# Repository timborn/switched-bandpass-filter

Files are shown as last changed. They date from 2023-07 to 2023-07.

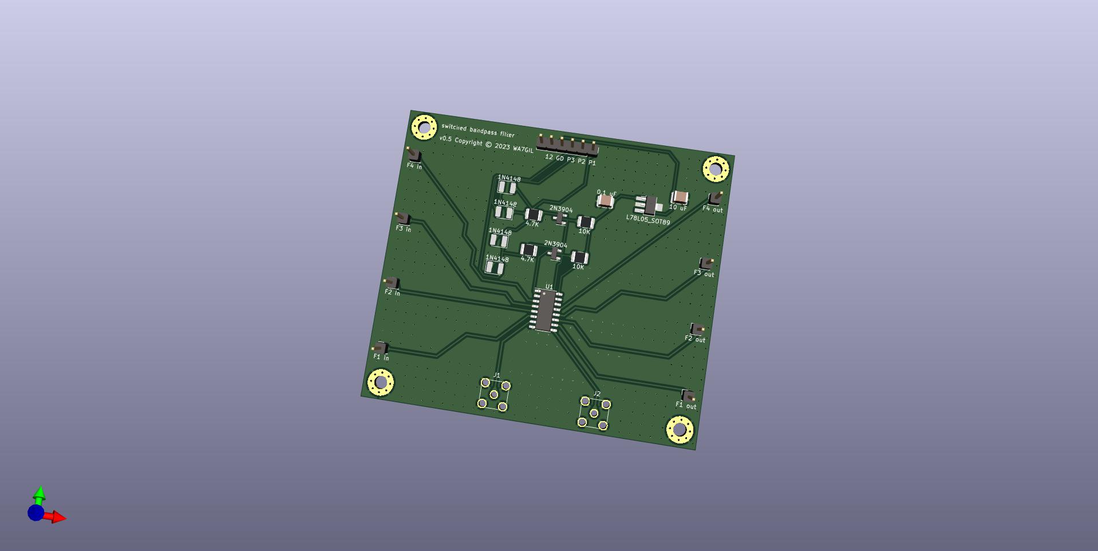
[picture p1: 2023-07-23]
docs/v0.5 3D front.jpg

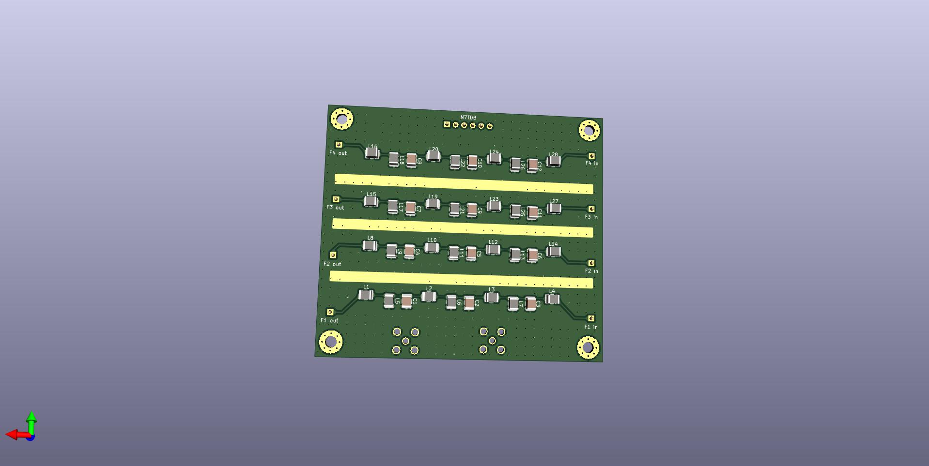
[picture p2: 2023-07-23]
docs/v0.5 3D back.jpg

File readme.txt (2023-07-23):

Thu Jul 20 09:18:21 MST 2023
----------------------------
Ron dropped off a couple of pages of hand drawn sketchs to make into a board.

CHANGE REQUESTS
X. change 4-pin header to 6-pin header
    Ron Taylor, 230719 4:47 PM
    Already thought I’d something. Please make it a 6pin header for the 
    switching so we can reference ground and have a spare too. Thanks
    
    tim born, 230719 4:48 PM
    6 pins instead of 4?  got it
2. correct board size appears to be 82x56mm
X. make sure to label Fx in/out on back of board!
4. DRC "solder mask aperture bridges items with different nets"
   SOT89 for 7805 has no solder bridge between pads for SMT part.
   I turned this error into a warning.  Don't know what I can do 
   to actually fix this.
X. fix this: single branch only using master
X. get rid of traces from front that route on the back
7. spread the connections from Fx in/out to U1 further apart
X. may not need full 15mm width for each of the filter runs
   squeeze them in and let Ron inspect
   we basically have a 56mm width minus SMA connectors minus headers
   there just isn't enough for 4*15mm filter strips
   Resolved: just jam them in.  Ron thinks they will fit.
X. increase board size and add mounting holes in the corners.
   3.25mm plated through and grounded, for 4-40 mounting h/w.
X. update board size on PCB viewer
X. traces to SMA are 50 ohm and need to be 3mm
X. add 3mm wide strips between filters by removing solder mask 
    so vertical boards could be soldered on
13. zeroed out "solder mask expansion" and "solder mask minimum web width"
    as I got stern warnings to use zero and let mfgr pick something suitable.
    Need to change the template.

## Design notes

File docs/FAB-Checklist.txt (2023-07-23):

Sun Jul 23 12:02:13 MST 2023
----------------------------

Checklist before you send it to the factory.

_X_ Update the page settings and version number on schematic & PCB.
    Check silkscreen version number!
_X_ ERC
_X_ Fill all pours!
_X_ run via stitcher
_X_ DRC
_X_ Generate Gerbers: 
    File / Plot  
    Layers: 
	F.Cu 
	B.Cu 
	F.Silkscreen 
	B.Silkscreen 
	F.Mask 
	B.Mask 
	Edge.Cuts
_X_ Generate Drill File.  Put output in same folder with Gerbers
_X_ verify Gerbers using Gerber Viewer in KiCad
    Suggested order: B.CU, B.Mask, B.Silkscreen, toggle each layer to 
    look for outliers.  Add Edge.Cuts.
    Repeat for F.*
_X_ zip up gerber/ into gerber.zip
_X_ PCBWAY
    NB anything but GREEN mask costs more!
    NB 83x73mm approx.  It's actually a couple mm larger than actual board.
_X_ git tag & push tags to origin

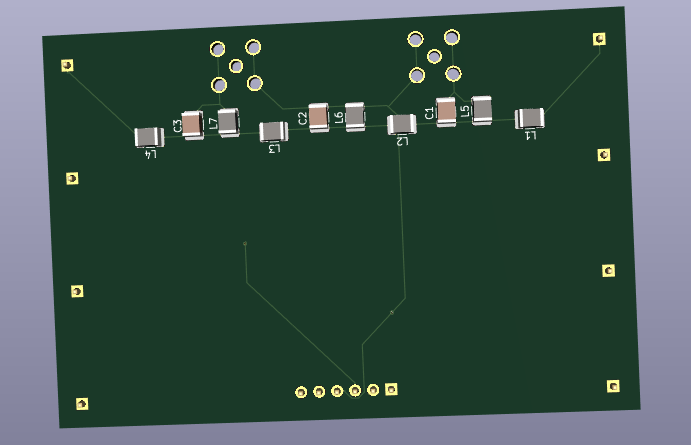
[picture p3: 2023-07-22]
docs/v0.2 3D back.png

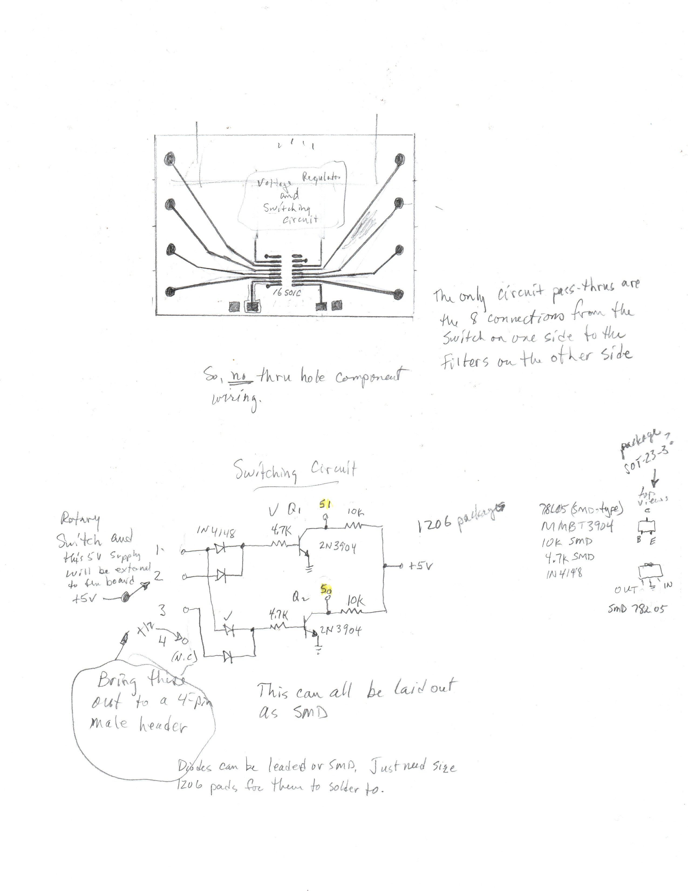
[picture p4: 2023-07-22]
docs/sketch-p1.jpg

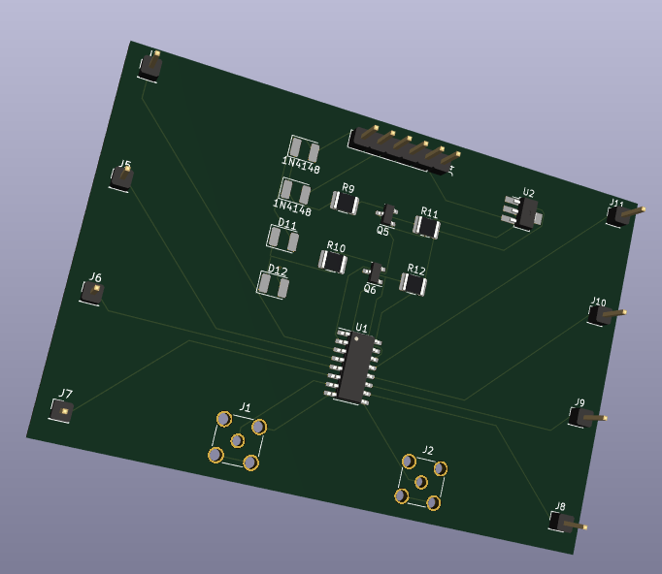
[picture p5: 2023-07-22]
docs/v0.2 3D front.png

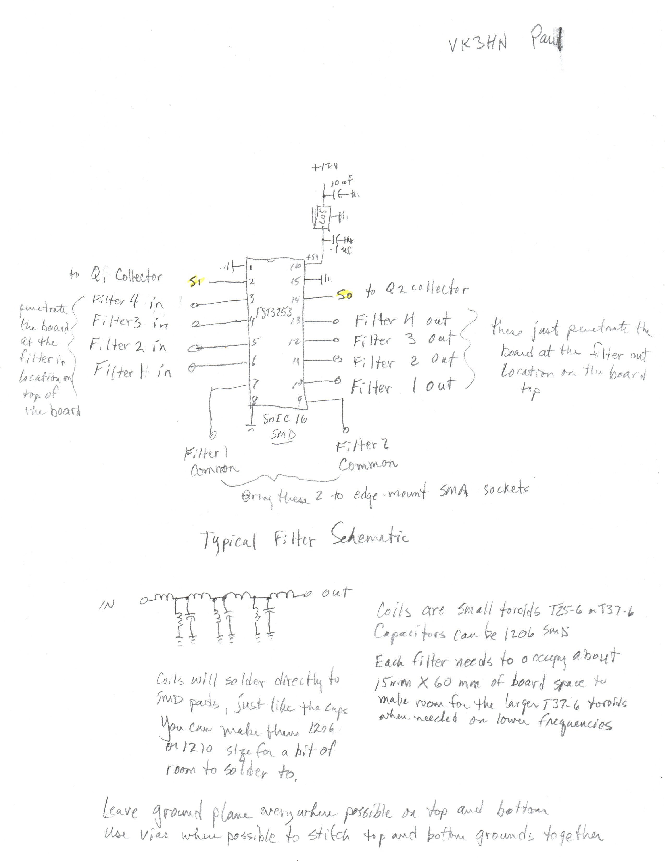
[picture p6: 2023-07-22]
docs/sketch-p2.jpg

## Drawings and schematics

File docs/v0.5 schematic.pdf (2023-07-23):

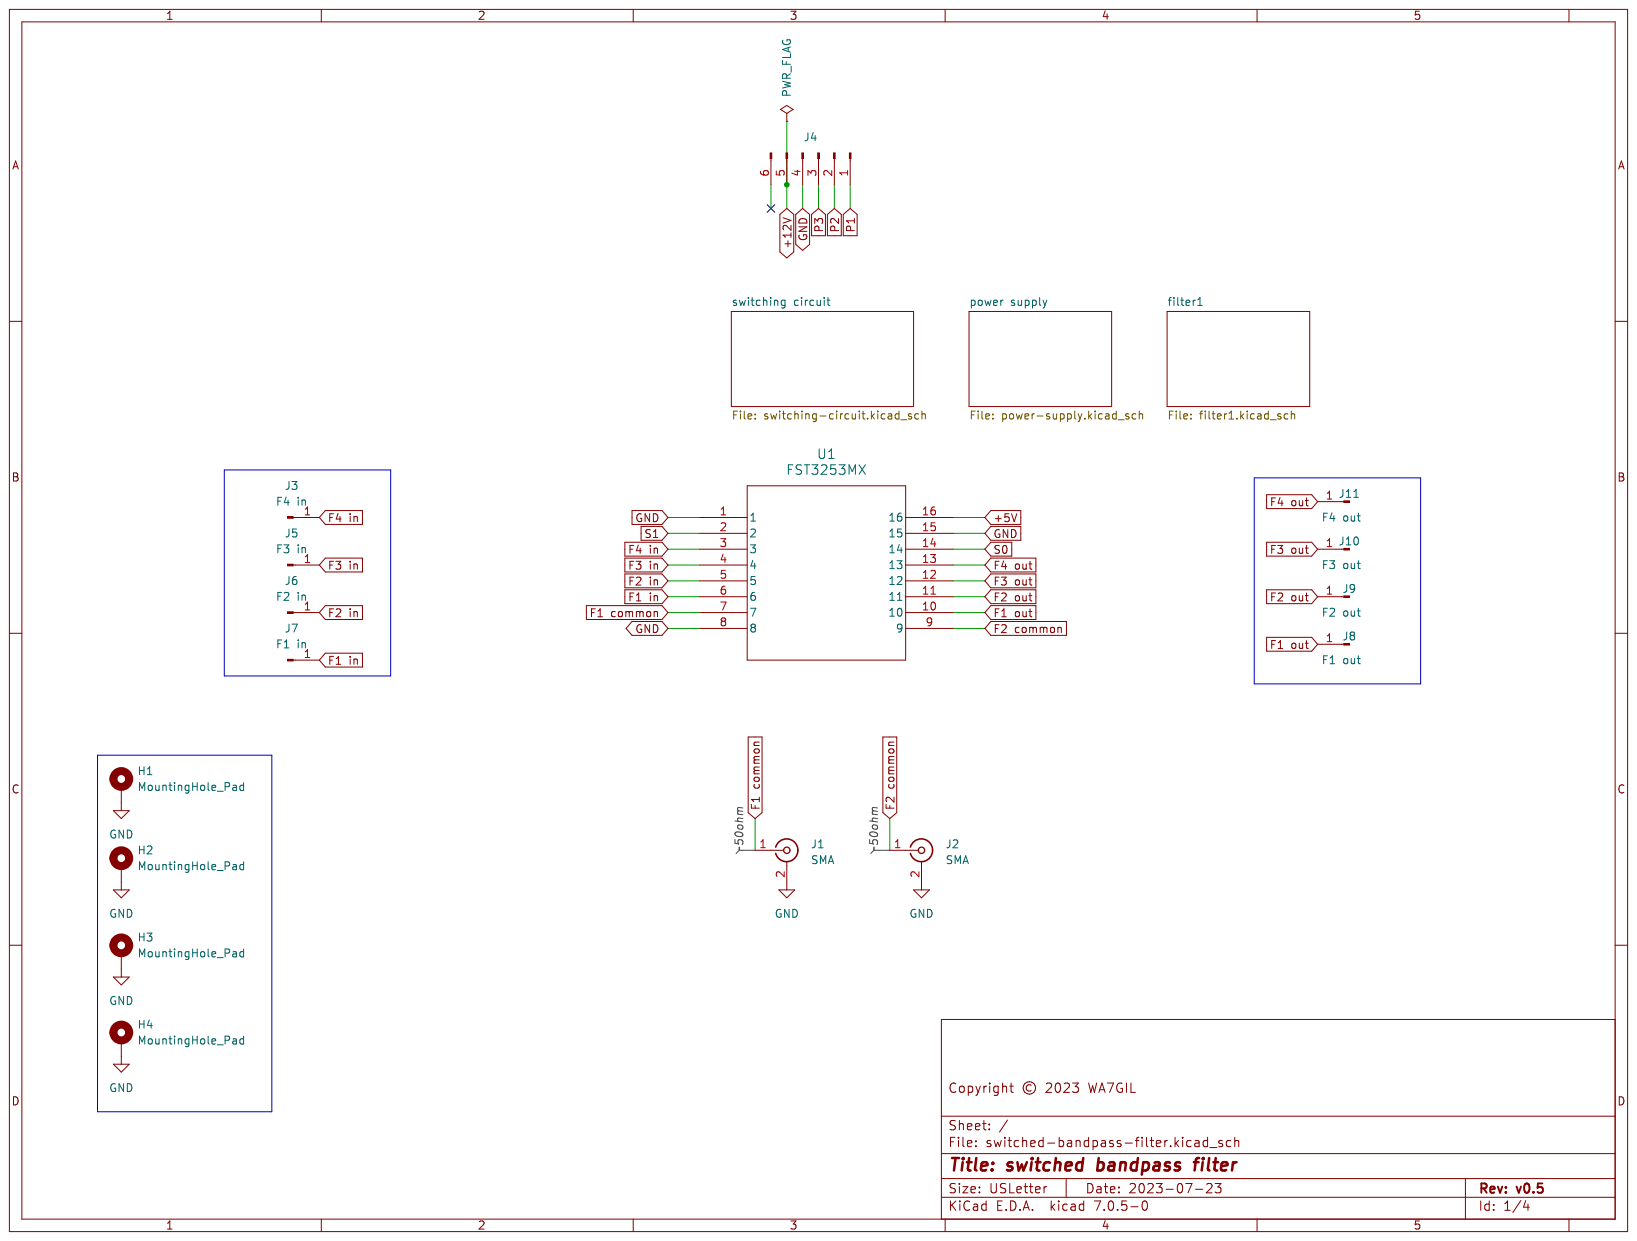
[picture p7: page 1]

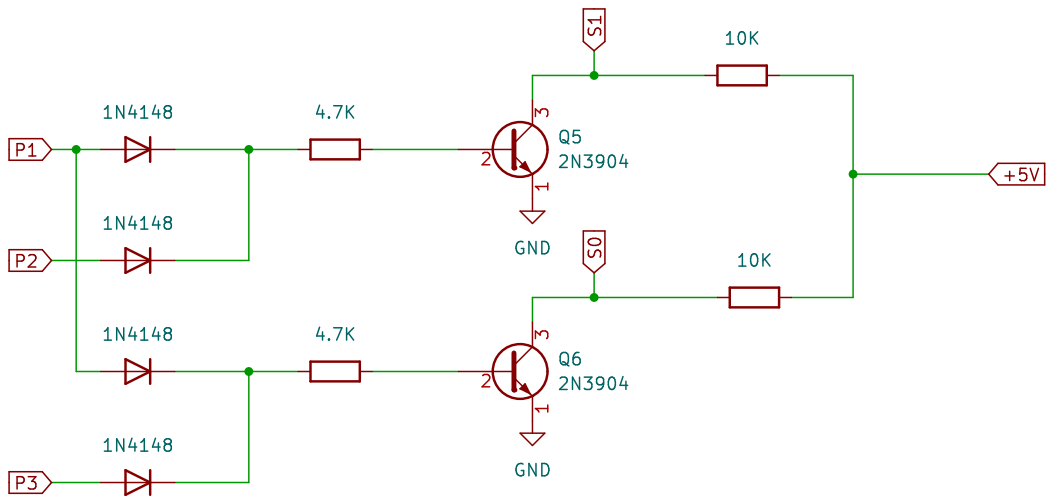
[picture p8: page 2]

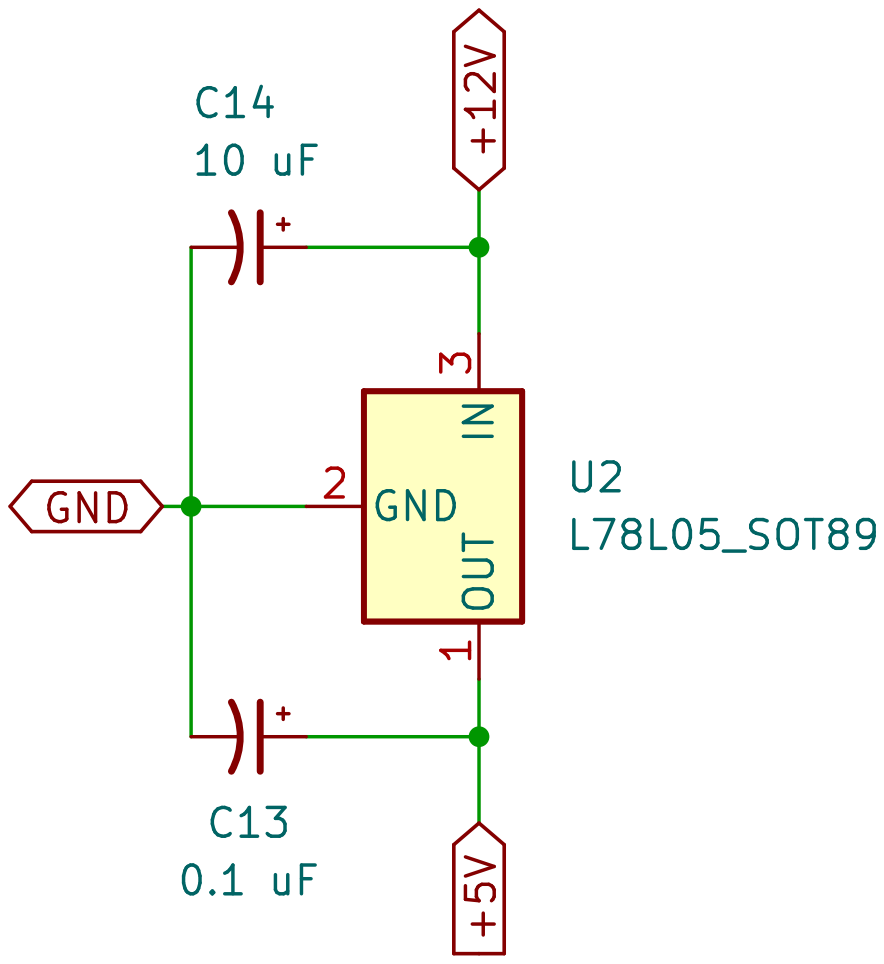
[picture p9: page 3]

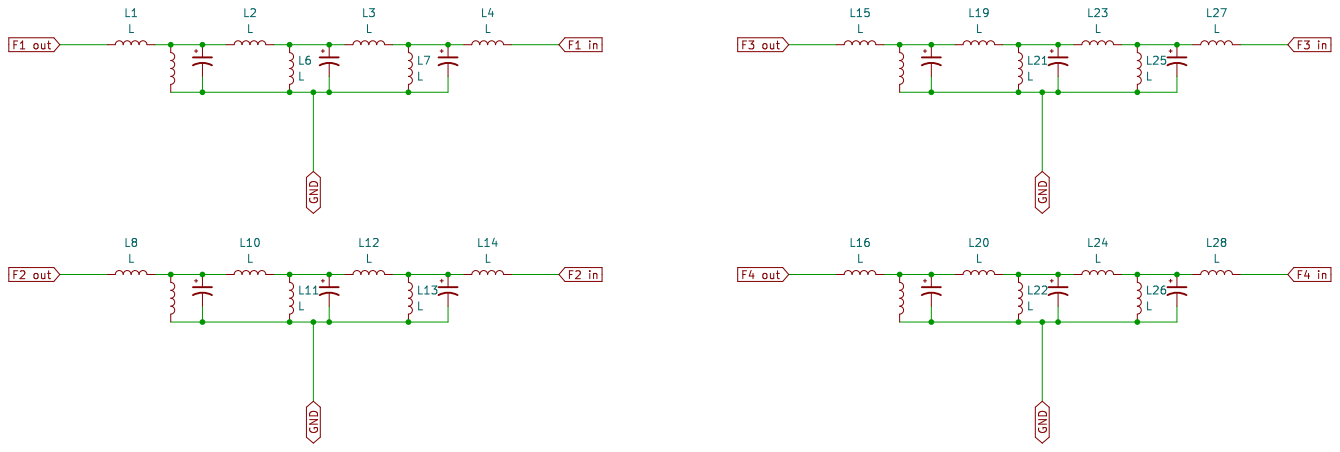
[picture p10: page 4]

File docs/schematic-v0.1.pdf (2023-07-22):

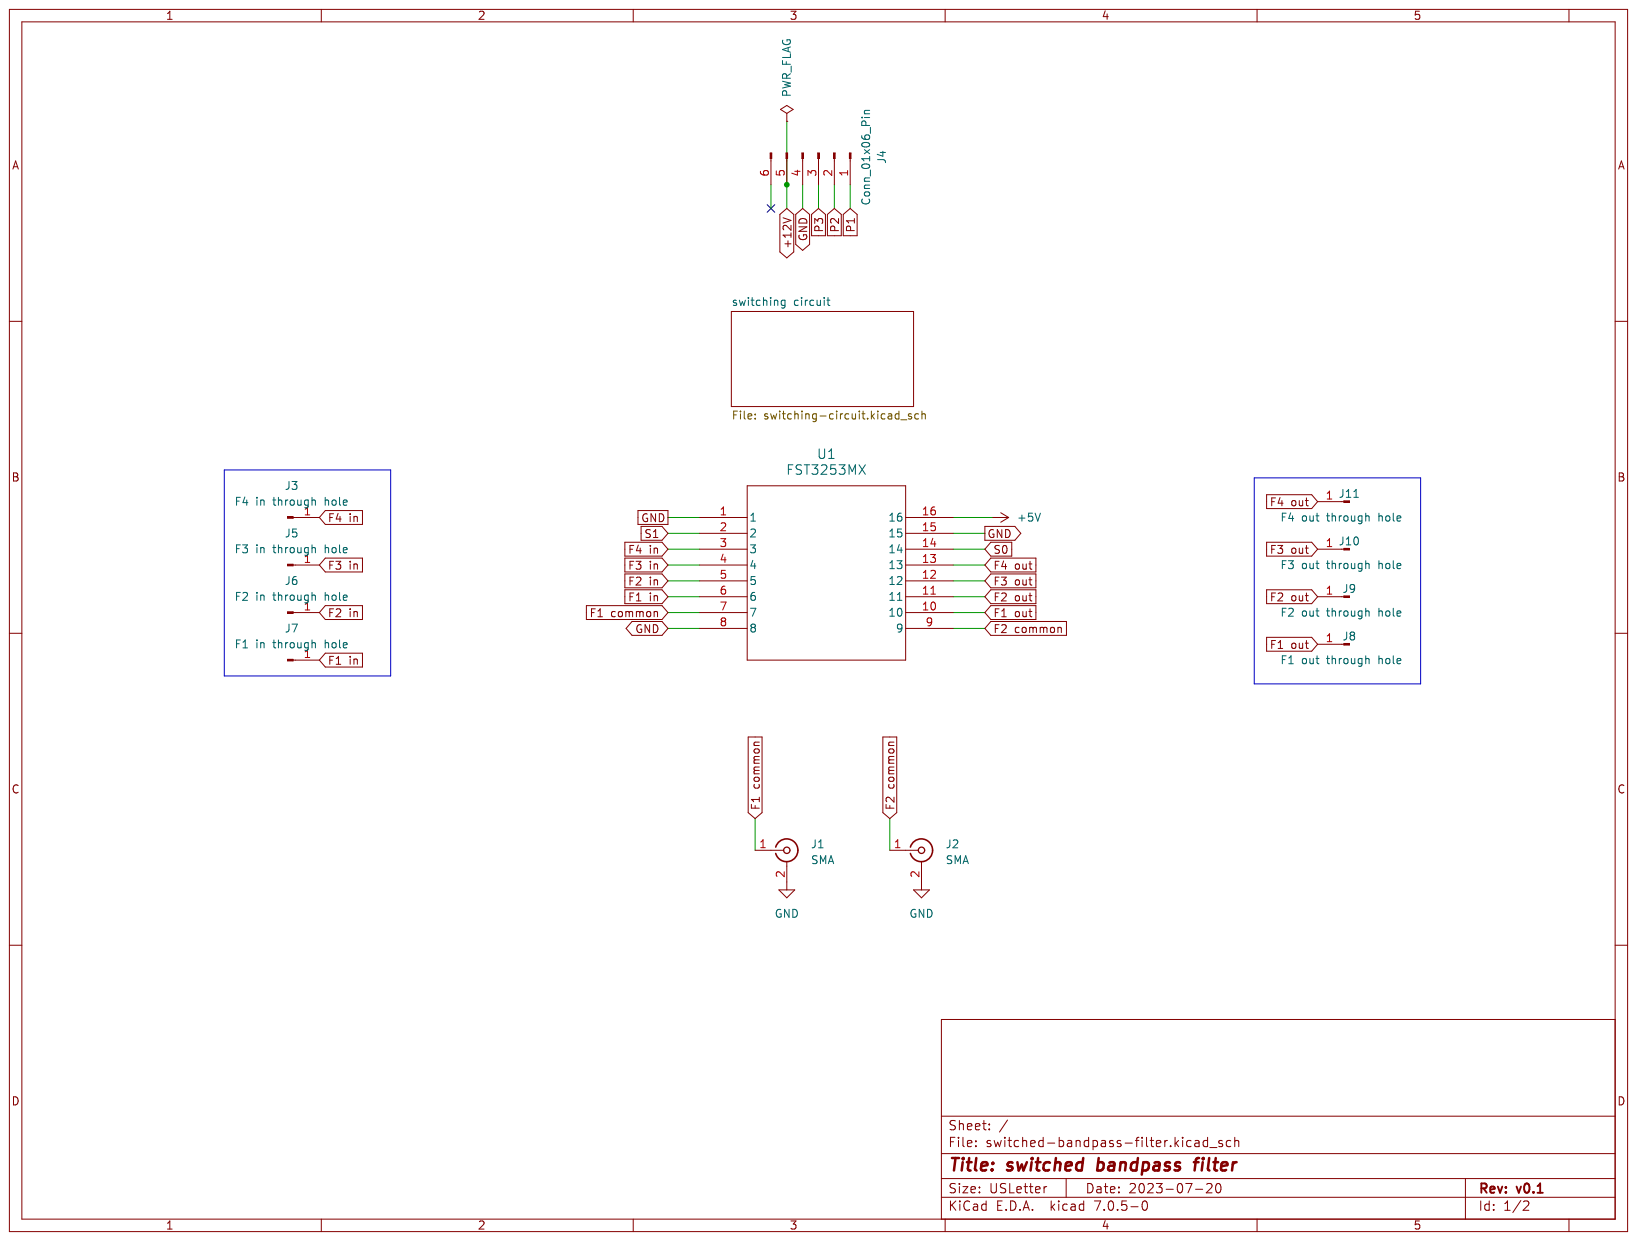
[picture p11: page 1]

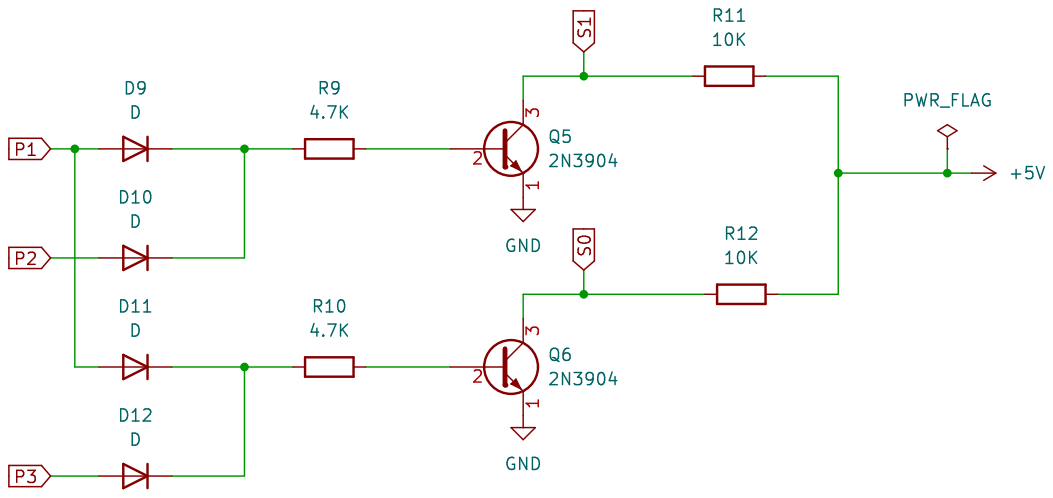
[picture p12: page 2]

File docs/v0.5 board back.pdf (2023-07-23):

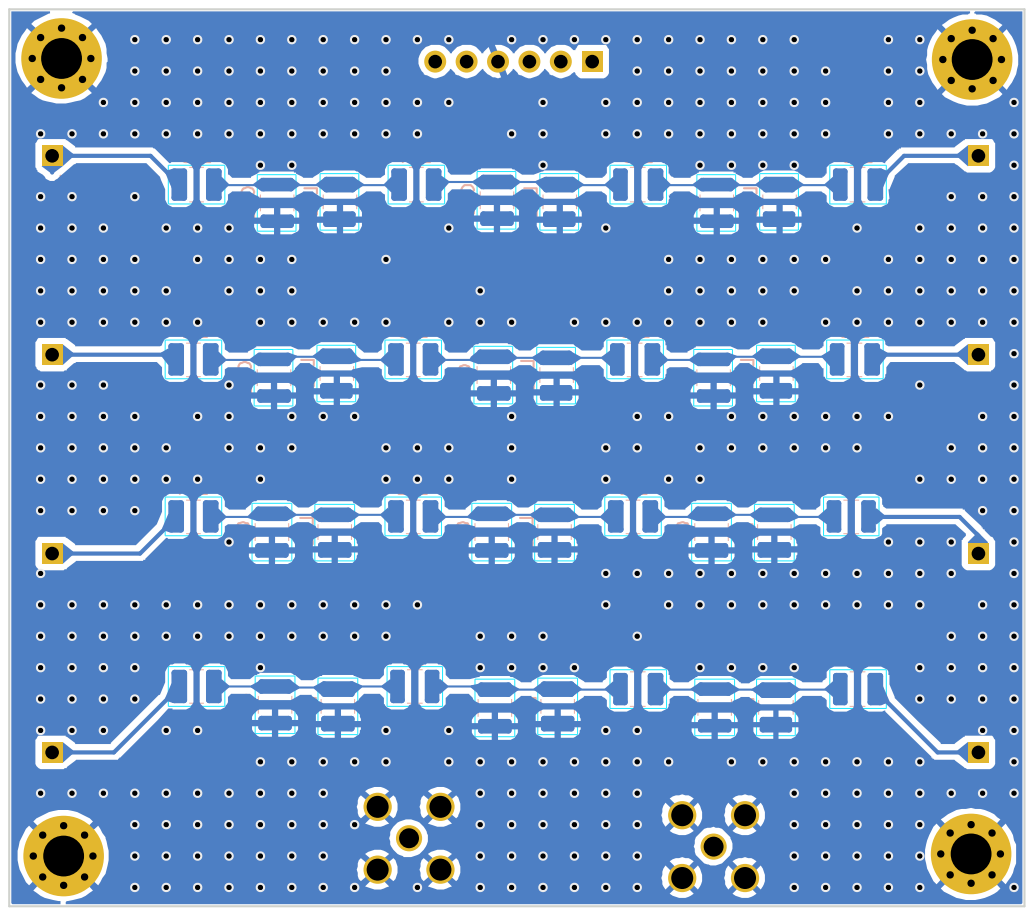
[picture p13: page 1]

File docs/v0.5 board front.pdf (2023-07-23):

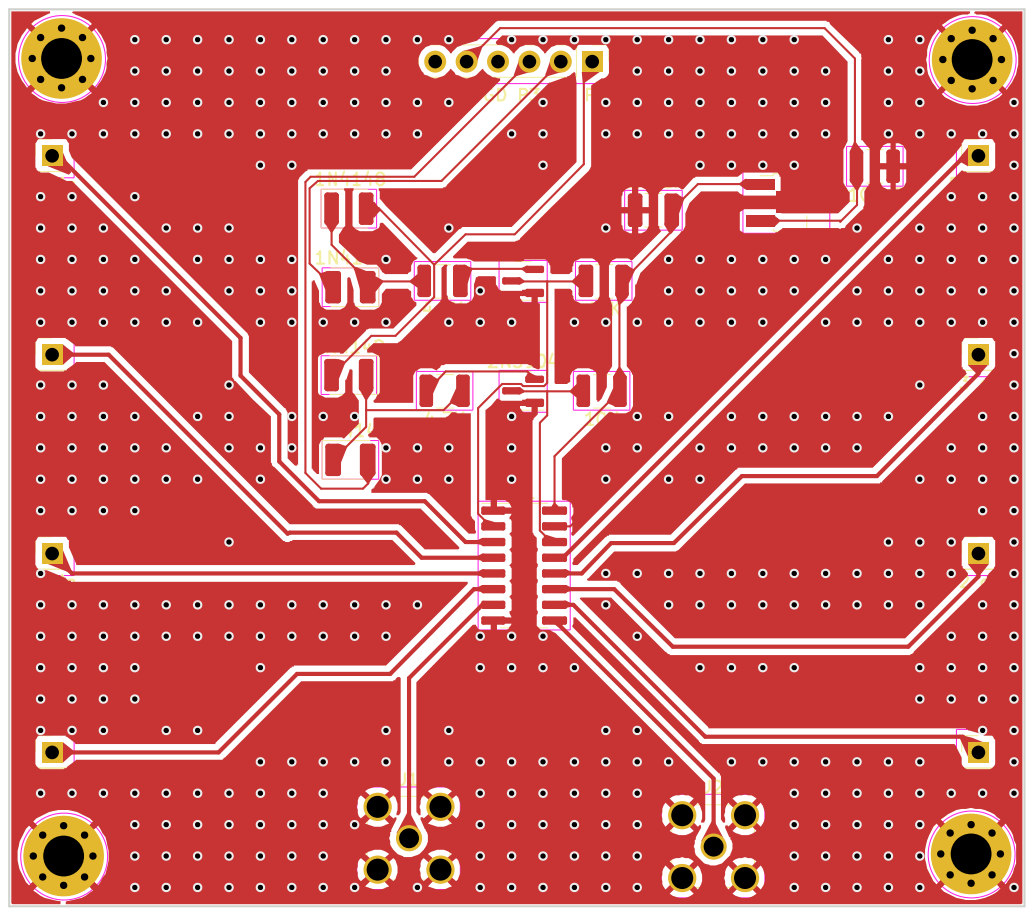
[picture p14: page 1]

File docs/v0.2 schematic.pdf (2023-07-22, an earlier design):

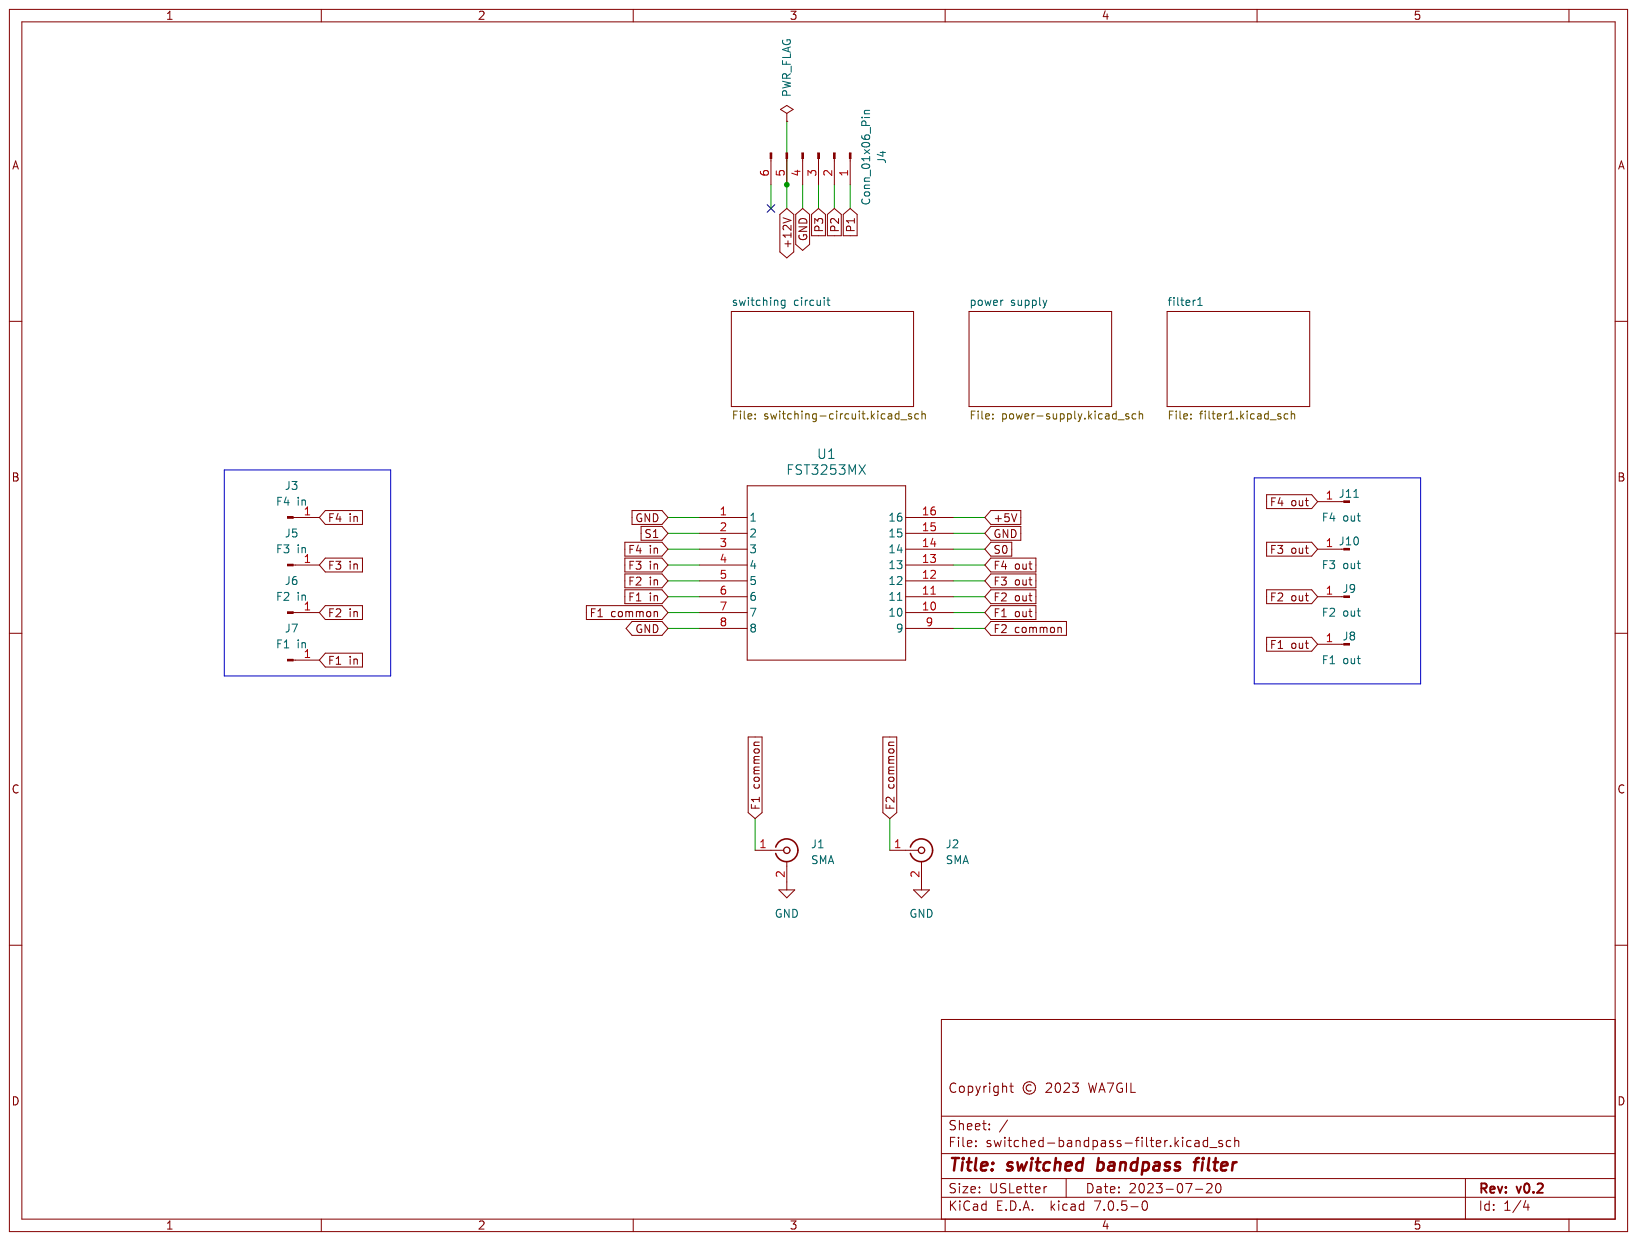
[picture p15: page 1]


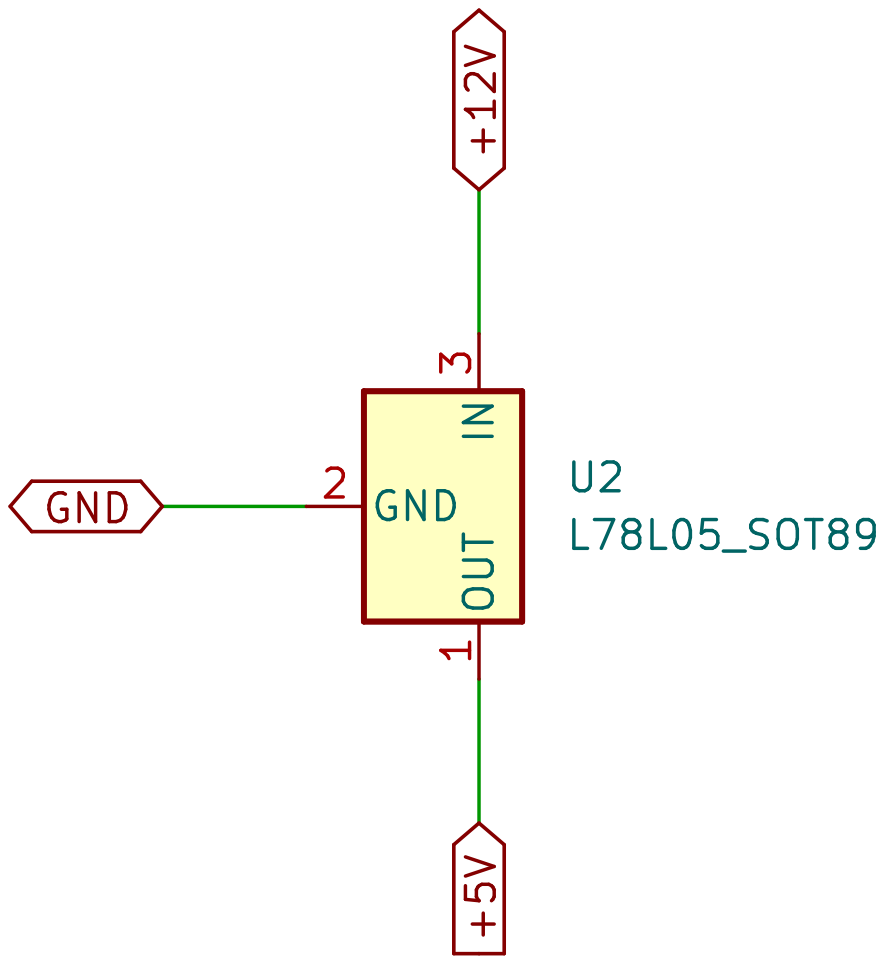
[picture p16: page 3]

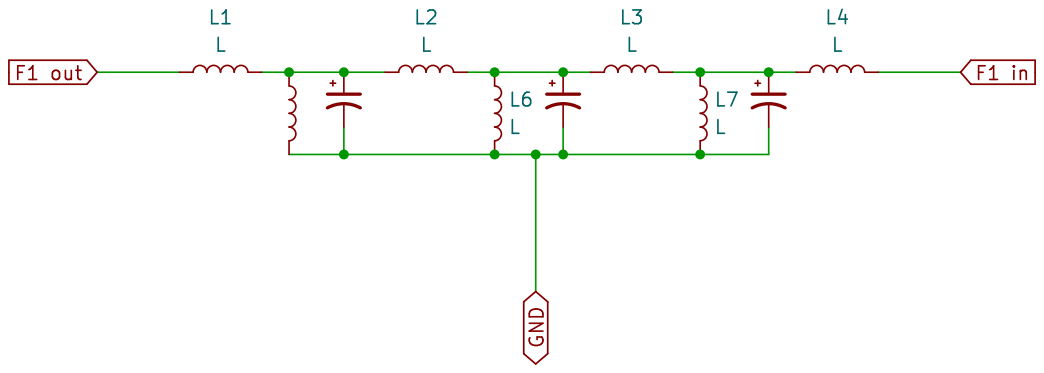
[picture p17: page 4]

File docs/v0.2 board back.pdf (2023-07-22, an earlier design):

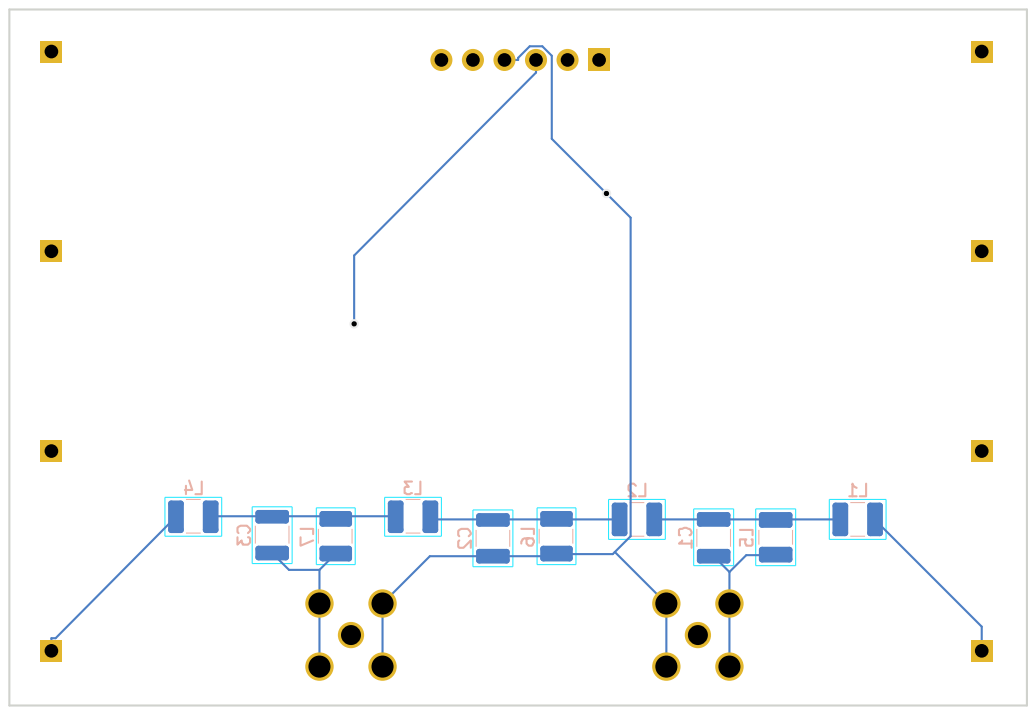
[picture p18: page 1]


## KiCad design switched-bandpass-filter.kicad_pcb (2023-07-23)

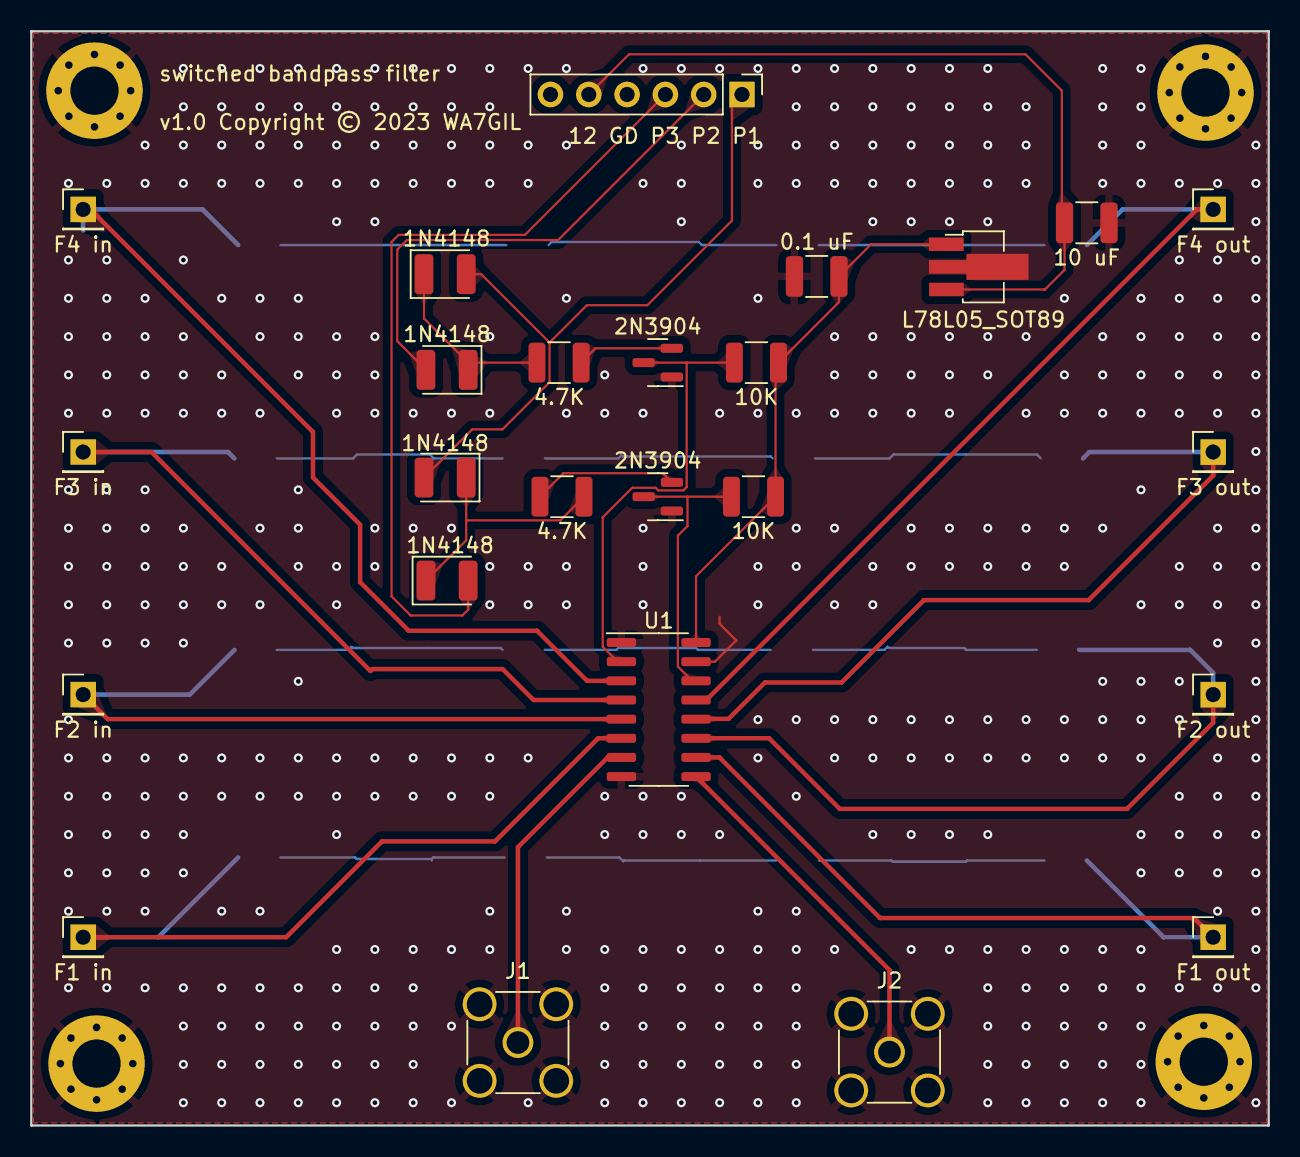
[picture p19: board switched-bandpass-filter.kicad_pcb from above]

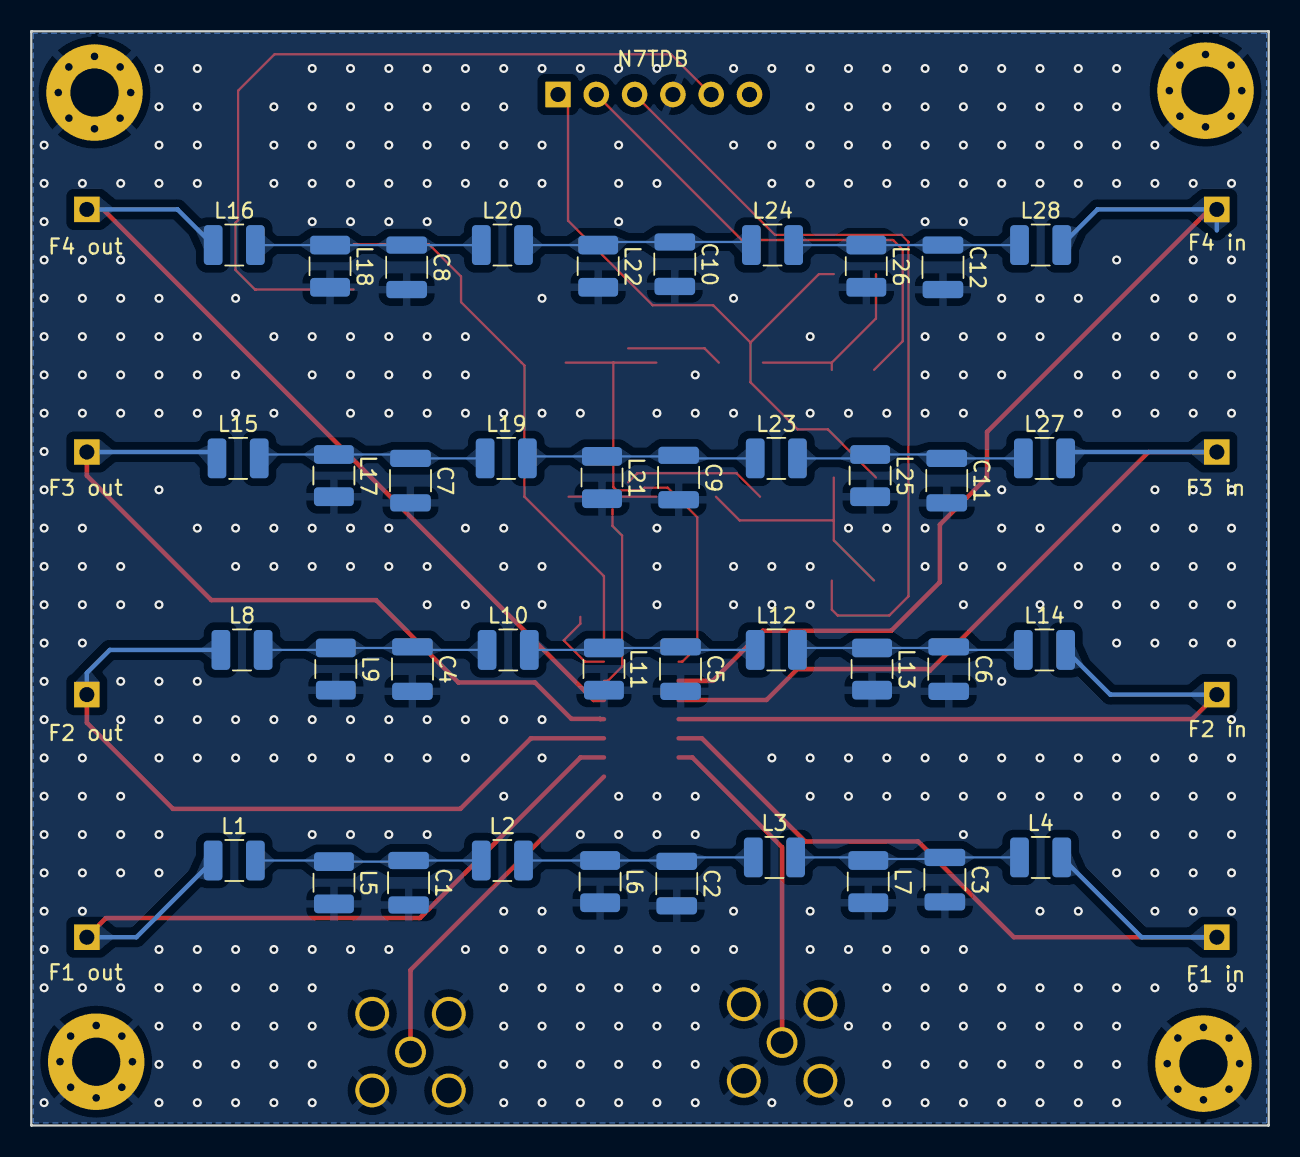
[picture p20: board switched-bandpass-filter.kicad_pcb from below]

Board: 2 copper layers, 82.1 x 72.6 mm, 69 parts (40 on the bottom side), 34 nets.

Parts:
C1, C2, C3, C4, C5, C6, C7, C8, C9, C10, C11, C12: C_1210_3225Metric
C13: 0.1 uF; C_1210_3225Metric
C14: 10 uF; C_1210_3225Metric
D9, D10, D11, D12: 1N4148; D_1210_3225Metric
H1, H2, H3, H4: MountingHole_3.2mm_M3_Pad_Via
J1, J2: SMA; SMA_Amphenol_901-144_Vertical
J3: F4 in; PinHeader_1x01_P2.54mm_Vertical
J4: PinHeader_1x06_P2.54mm_Vertical
J5: F3 in; PinHeader_1x01_P2.54mm_Vertical
J6: F2 in; PinHeader_1x01_P2.54mm_Vertical
J7: F1 in; PinHeader_1x01_P2.54mm_Vertical
J8: F1 out; PinHeader_1x01_P2.54mm_Vertical
J9: F2 out; PinHeader_1x01_P2.54mm_Vertical
J10: F3 out; PinHeader_1x01_P2.54mm_Vertical
J11: F4 out; PinHeader_1x01_P2.54mm_Vertical
L1, L2, L3, L4, L5, L6, L7, L8, L9, L10, L11, L12, L13, L14, L15, L16, L17, L18, L19, L20, L21, L22, L23, L24, L25, L26, L27, L28: L; L_1210_3225Metric
Q5, Q6: 2N3904; SOT-23
R9, R10: 4.7K; R_1210_3225Metric
R11, R12: 10K; R_1210_3225Metric
U1: FST3253MX; SOIC-16_3.9x9.9mm_P1.27mm
U2: L78L05_SOT89; SOT-89-3_Handsoldering

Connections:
+5V: C13.1, R11.2, R12.2, U1.16, U2.1 (OUT)
+12V: C14.1, J4.5, U2.3 (IN)
F1 common: J1.1 (In), U1.7
F1 in: J7.1, L4.2, U1.6
F1 out: J8.1, L1.1, U1.10
F2 common: J2.1 (In), U1.9
F2 in: J6.1, L14.2, U1.5
F2 out: J9.1, L8.1, U1.11
F3 in: J5.1, L27.2, U1.4
F3 out: J10.1, L15.1, U1.12
F4 in: J3.1, L28.2, U1.3
F4 out: J11.1, L16.1, U1.13
GND: C1.2, C2.2, C3.2, C4.2, C5.2, C6.2, C7.2, C8.2, C9.2, C10.2, C11.2, C12.2, C13.2, C14.2, H1.1, H2.1, H3.1, H4.1, J1.2 (Ext), J2.2 (Ext), J4.4, L5.2, L6.2, L7.2, L9.2, L11.2, L13.2, L17.2, L18.2, L21.2, L22.2, L25.2, L26.2, Q5.1 (E), Q6.1 (E), U1.1, U1.8, U1.15, U2.2 (GND)
unnamed: C1.1, L1.2, L2.1, L5.1
unnamed: C2.1, L2.2, L3.1, L6.1
unnamed: C3.1, L3.2, L4.1, L7.1
unnamed: C4.1, L8.2, L9.1, L10.1
unnamed: C5.1, L10.2, L11.1, L12.1
unnamed: C6.1, L12.2, L13.1, L14.1
unnamed: C7.1, L15.2, L17.1, L19.1
unnamed: C8.1, L16.2, L18.1, L20.1
unnamed: C9.1, L19.2, L21.1, L23.1
unnamed: C10.1, L20.2, L22.1, L24.1
unnamed: C11.1, L23.2, L25.1, L27.1
unnamed: C12.1, L24.2, L26.1, L28.1
unnamed: D9.1 (K), D10.1 (K), R9.1
unnamed: D11.1 (K), D12.1 (K), R10.2
unnamed: Q5.2 (B), R9.2
unnamed: Q6.2 (B), R10.1
P1: D9.2 (A), D11.2 (A), J4.1
P2: D10.2 (A), J4.2
P3: D12.2 (A), J4.3
S0: Q6.3 (C), R12.1, U1.14
S1: Q5.3 (C), R11.1, U1.2

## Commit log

2023-07-20 made a start on schematic, and ERC passes
    [foobar.kicad_sch, switched-bandpass-filter.kicad_sch, switching-circuit.kicad_sch]
2023-07-20 added power supply schematic, and deleted the -backups folder
    [power-supply.kicad_sch, switched-bandpass-filter.kicad_sch, switching-circuit.kicad_sch]
2023-07-20 added filter ckt, passes ERC, bumped to v0.2, ready for board layout
    [filter1.kicad_sch, power-supply.kicad_sch, switched-bandpass-filter.kicad_sch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]
2023-07-21 v0.2 passes ERC & DRC except for no solder mask between pads on SOT89
    [filter1.kicad_sch, power-supply.kicad_sch, switched-bandpass-filter.kicad_pcb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]
2023-07-22 v0.3 added all four filters. ERC pass, DRC struggling. Need a ground plane
    [filter1.kicad_sch, power-supply.kicad_sch, switched-bandpass-filter.kicad_pcb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]
2023-07-22 v0.3 ERC pass, DRC two unconnected. Stitching ground planes may solve this.
    [switched-bandpass-filter.kicad_pcb]
2023-07-22 v0.3 ERC/DRC pass; via stitch in place. Time for a squint
    [switched-bandpass-filter.kicad_pcb]
2023-07-23 v0.4 ERC/DRC pass; added missing caps; mounting holes; moved SMA & headers out and re-spaced filter chains
    [filter1.kicad_sch, power-supply.kicad_sch, switched-bandpass-filter.kicad_pcb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]
2023-07-23 starting on v0.5
    [filter1.kicad_sch, power-supply.kicad_sch, switching-circuit.kicad_sch]
2023-07-23 v0.5 SMA traces now 0.3mm for 50 ohms
    [switched-bandpass-filter.kicad_pcb, switched-bandpass-filter.kicad_sch]
2023-07-23 removed stitched ground plane and shifted filter #3 to make space for 3mm gap in silk screen
    [switched-bandpass-filter.kicad_pcb]
2023-07-23 slowly approaching cutting out 3mm strips from solder mask on rear
    [switched-bandpass-filter.kicad_pcb]
2023-07-23 many of the FAB markings wanted to be silkscreen, and visaversa
    [switched-bandpass-filter.kicad_pcb]
2023-07-23 v0.5 ATP; 3mm wide strips between filters; 3mm traces to SMA
    [switched-bandpass-filter.kicad_pcb]
2023-07-23 supress display of 1x1 headers for Fx in/out. Had to supress warnings from DRC as well, since selected component no longer matches what is displayed. It is intended to be an empty plated through hole.
    [switched-bandpass-filter.kicad_pcb, switched-bandpass-filter.kicad_sch]
2023-07-23 v1.0 shipped to PCBWay
    [filter1.kicad_sch, power-supply.kicad_sch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]

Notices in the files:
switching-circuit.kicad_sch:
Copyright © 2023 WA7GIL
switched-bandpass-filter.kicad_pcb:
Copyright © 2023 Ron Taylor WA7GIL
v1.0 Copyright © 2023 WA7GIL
